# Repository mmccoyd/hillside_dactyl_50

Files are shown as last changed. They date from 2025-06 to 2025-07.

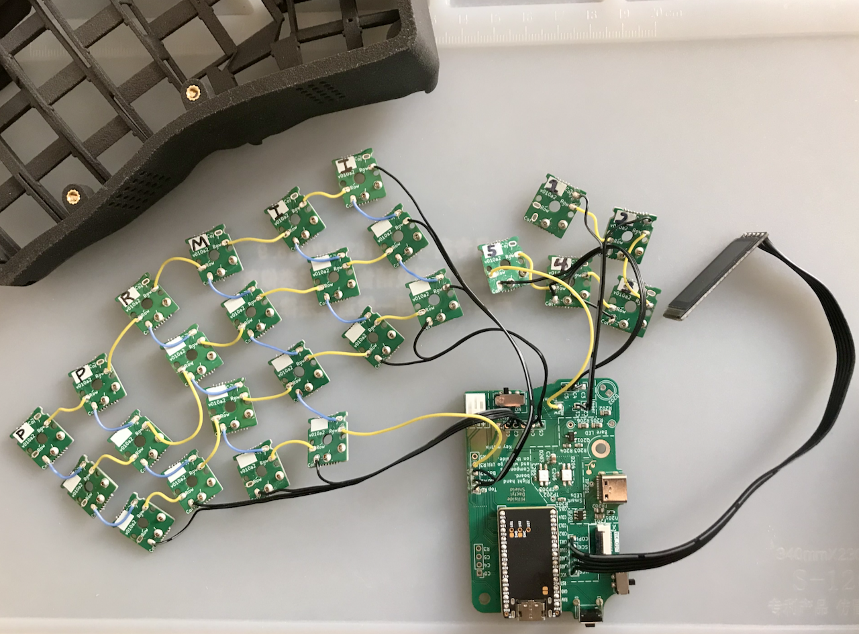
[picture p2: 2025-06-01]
image/D50_build_boards.png

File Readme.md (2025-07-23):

# Hillside Dactyl 50

D50 above

The Hillside Dactyl 50 is a small contoured-keywell ergonomic keyboard
    with three choc-spaced rows of six per side.
This repository has the [body files](./stl/),
    and describes parts and assembly in the 
    [wiki](https://github.com/mmccoyd/hillside_dactyl_50/wiki).

Two other repositories have the PCB files

-   [Amoeba Choc14](https://github.com/mmccoyd/hillside_amoeba_choc14)
    to wire the switches and diodes to create the key matrix.
-   [Hillside Dactyl Shield](https://github.com/mmccoyd/hillside_dactyl_shield)
    to connect the MCU, keys, display, and LEDs.

Though still in development, it has been reliable and comfortable.
See the [Chgange log](./ChangeLog.md) for known issues, but
    I hope you find the board useful.

## Features

-   Three main rows of six, a lower row of two, five thumb keys, and 50 keys
    total.
-   A keywell with 15° column curve, and 15° tent built in.
-   A [Dactyl](https://github.com/adereth/dactyl-keyboard) style thumb cluster
    with a pressing-down motion not a
    gripping one.
-   Choc v1 18 x 17 mm spacing, often nicer for medium or smaller hands.
-   Wireless focused, yet with a wired split USB-C with ESD protection.
-   An external switches header for foot pedals, but case drilling would be
    needed.
-   Default key maps for
    [ZMK](https://github.com/mmccoyd/zmk-hillsideD50) as an external module and
    [QMK](https://github.com/mmccoyd/qmk_firmware/tree/hillside_d50/keyboards/hillside/d50)
    as a branch on a fork.

### Non-Features

-   Switch insertion or replacement externally.
    The case needs to be open to press the amoebas up onto the switches.
    The switches snap into the case, but the amoeba don't.
    The amoeba are held in place by a tight grip on the switch's plastic posts.
    Switches popping out is rare when dropped, but is possible.
    Iterating on this is on my list of longer term items.
-   Per key RGB.
    The amoebas don't have much space.
    It would be cool and might be possible, but is low on my priority list.

## Future

For non-breaking changes:
    the display corner could use more smoothing,
    front magnets spots would allow a palm rest,
    and, as a larger change, a CNC steel bottom plate would give a wider
    base for tenting adjustments and could lower the height a few mm.

The development branch folder
    [stl_dev/](https://github.com/mmccoyd/hillside_dactyl_50/tree/dev/stl_dev)
    may have *untested* files with some of these changes.

Eventually there will be a breaking change to eliminate the external recesses
    for the USB plug overmolding.
A matching new shield design will be needed that extends the USB into the
    inner walls.
But this will be a while.

I don't foresee changes to the basic key configuration,
    such as a five column version.
But I'm working to release STEP and source files for the amoeba socket
    to help others who want to create small choc dactyls.

## License

This work is licensed under a
[Creative Commons Attribution-NonCommercial-ShareAlike 4.0 International](
https://creativecommons.org/licenses/by-nc-sa/4.0/) license.

## See also

This Dactyl evolved from my ergonomic but flat
    [Hillside keyboards](https://github.com/mmccoyd/hillside),
    which offer easier starting points for those new to small choc-spaced
    ergonomic boards.

The general reasons for
    [split contoured-keywells](https://www.ergocanada.com/detailed_specification_pages/kinesis_corporation_advantage360_pro_contoured_keyboard.html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)
    and [small keyboards](https://40s.wiki/en/why) may explain why
    this board can be nice to use.

This Dactyl fits me well and I think likely others with medium hands.
But a roughly good fit is important in a Dactyl, so the below are valuable
    alternatives.

Some prebuild Dactyls include
    the larger [Kinesis Advantage 360](https://kinesis-ergo.com/shop/adv360pro/)
    and [MoErgo Glove 80](https://www.moergo.com/);
    while [Bastard Keyboards](https://bastardkb.com/) has prebuilt
    medium to small
    [Dactyl Manuforms](https://github.com/abstracthat/dactyl-manuform).
Some argue that the original
    [Dactyl](https://github.com/adereth/dactyl-keyboard)
    is gentler on the thumb joint and wrist than the
    [Dactyl Manuform](https://github.com/abstracthat/dactyl-manuform) is.
The Glove 80 is the only of these prebuilt with choc spaced switches, 
    which are nice for medium or smaller hands.

[Cosmos](https://ryanis.cool/cosmos/) is a great generator for custom Dactyl
    Manuform bodies that can do choc vertical but gives thickness warnings for
    choc horizontal spacing.
It offers a prebuilt option and allows broad changes to board parameters.
Including changing the position and angle of the entire thumb
    cluster, with the select cluster and edit cluster controls,
    to make it more original Dactyl like or not.

Two choc v1 boards with contoured body columns,
    though no home-row height variation, are the
    [juriform36](https://github.com/jurica/juriform36) and the
    [rkbrd3](https://github.com/prepor/rkbrd/tree/main/3).
YellowAfterlife's
    [ergonomic keyboard list](https://yal-tools.github.io/ergo-keyboards/)
    shows a few more contoured keywell options and many flat options.

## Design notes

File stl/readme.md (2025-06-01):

# STL files

The files here are for:

-   Left and right body parts - usually 3D printed in nylon or resin.
    -   Upper
    -   Bottom plate
    -   Keywell wiring aid
    -   Thumb wiring aid
-   Non-sided parts
    -   Magnetic tenting oval - likely laser cut from spring steel.
        A standard phone ring is an alternative.
        But it doesn't offer as much ease of tenting adjustment or angle.
    -   Display mount washer - likely laser cut from spring steel.
        There are other ways to secure the display, such as hot glue
        or very likely some normal washer.
        But the case is designed to use the laser cut tenting disk,
        so a laser cut washer is easy to source with that.
    -   Rear laptop hook - usually 3D printed

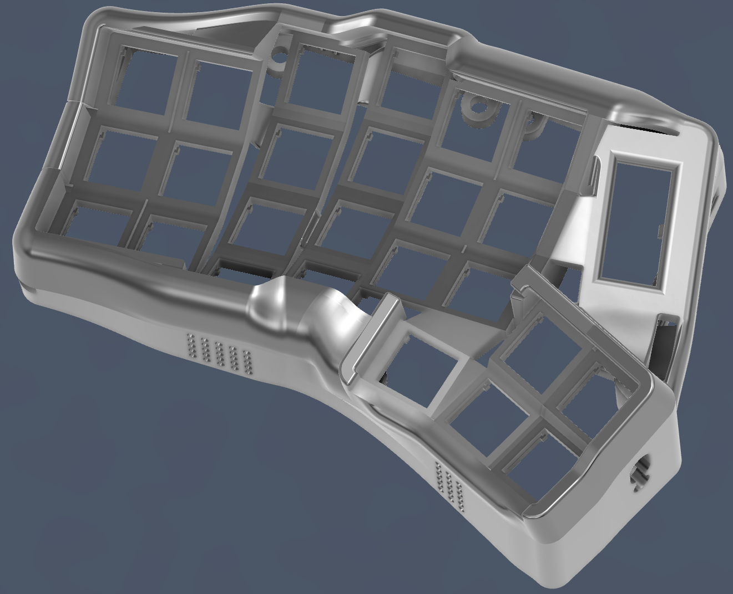
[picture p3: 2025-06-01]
image/D50_render_left.png

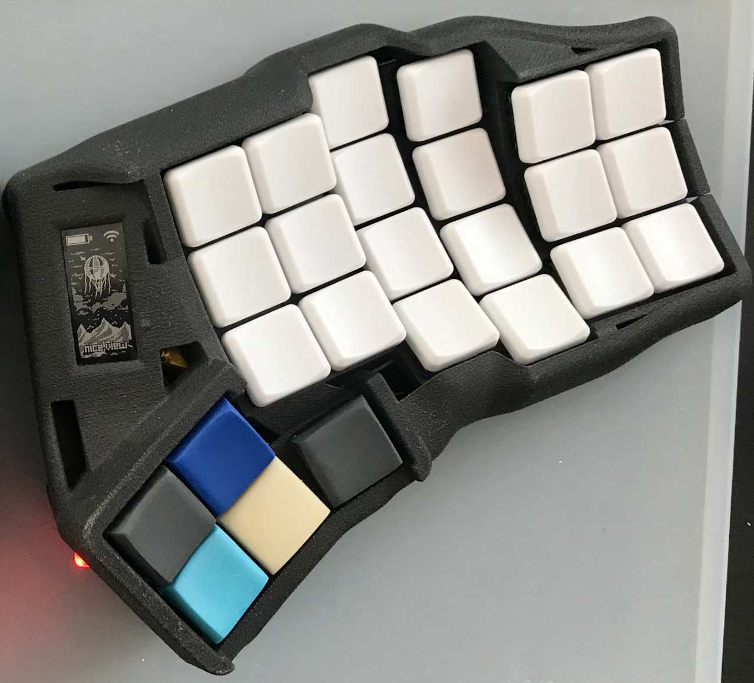
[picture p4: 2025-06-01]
image/D50_right.png

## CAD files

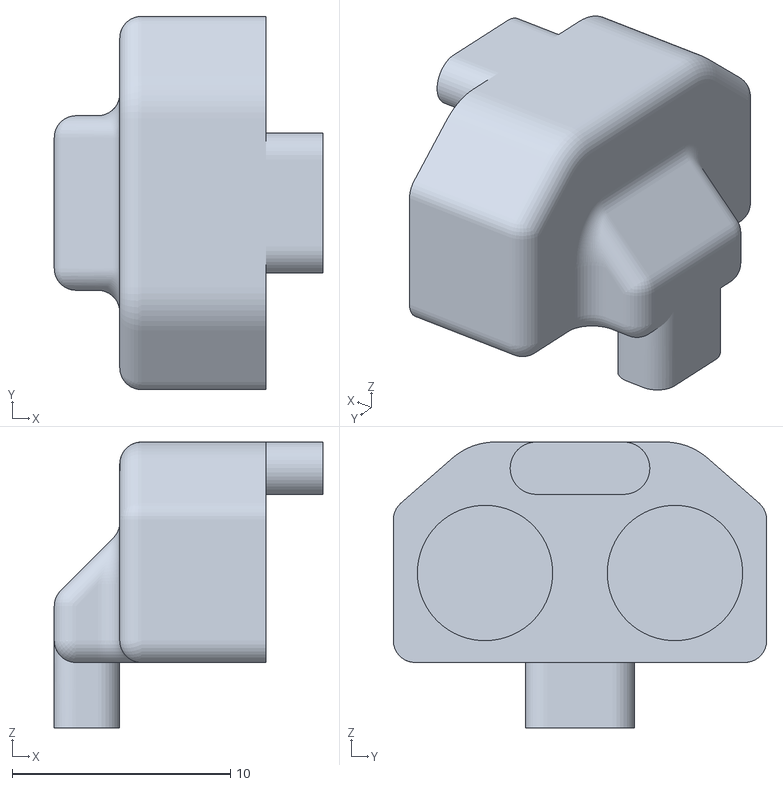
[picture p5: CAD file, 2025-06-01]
stl/HilD50_hook.stl
12.3 x 17.1 x 13.1

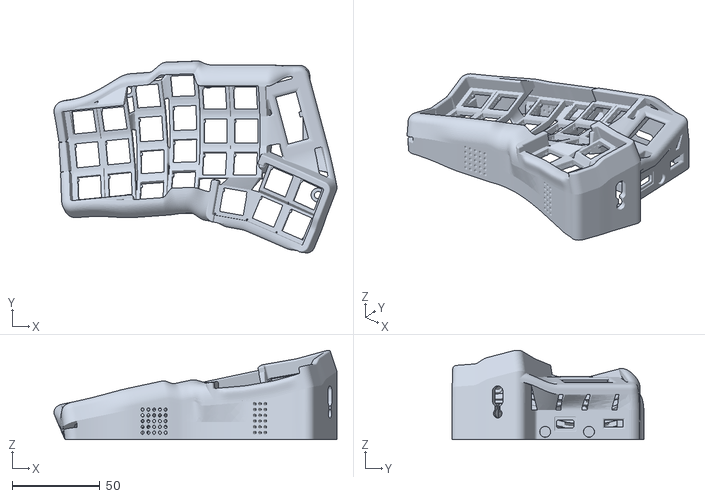
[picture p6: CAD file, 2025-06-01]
stl/left/HilD50_upper_L.stl
161.7 x 109.6 x 51.0

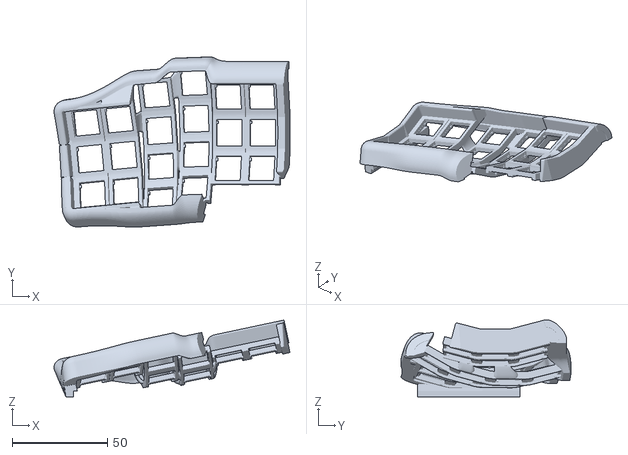
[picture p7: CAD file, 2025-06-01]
stl/left/HilD50_keywell_L.stl
124.2 x 89.5 x 40.5

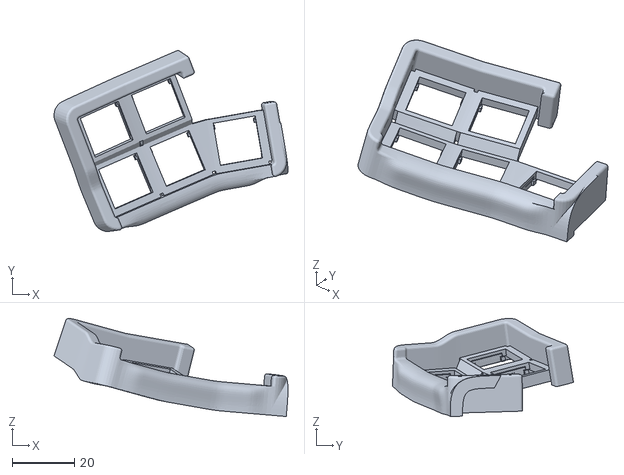
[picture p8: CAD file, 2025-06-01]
stl/right/HilD50_thumb_R.stl
75.3 x 58.3 x 31.6

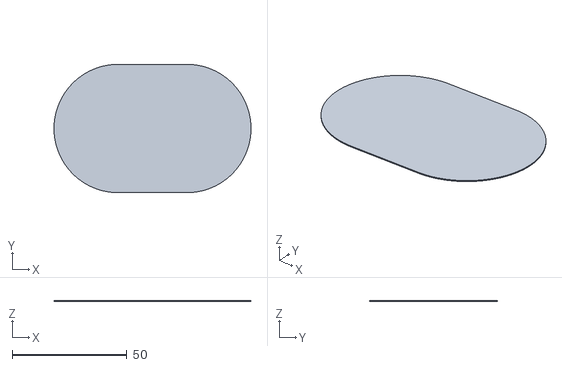
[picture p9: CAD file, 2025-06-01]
stl/HilD50_mag_mount.stl
86.0 x 56.0 x 0.38

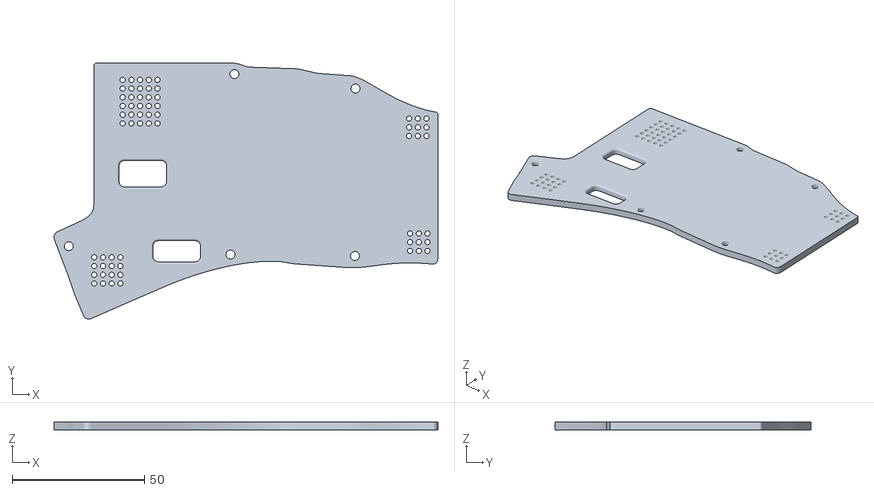
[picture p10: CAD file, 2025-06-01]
stl/right/HilD50_bottom_R.stl
145.4 x 97.0 x 3.00

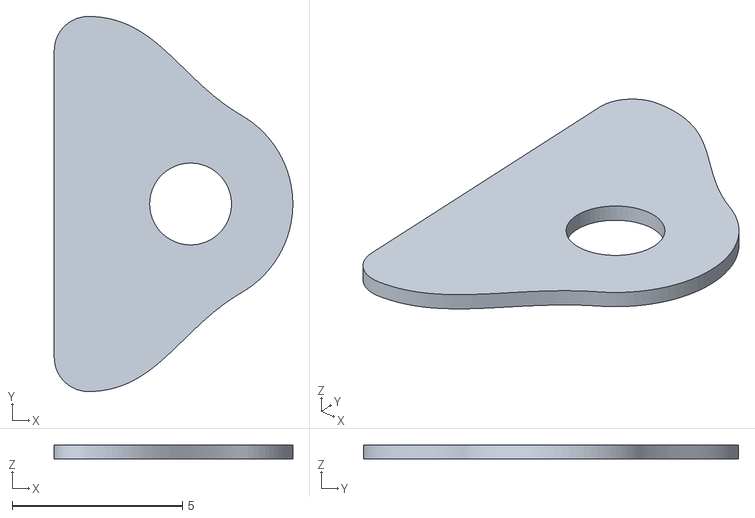
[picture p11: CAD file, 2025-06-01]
stl/HilD50_disp_washer.stl
7.00 x 11.0 x 0.4

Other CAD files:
stl/right/HilD50_upper_R.stl
stl/left/HilD50_thumb_L.stl
stl/left/HilD50_bottom_L.stl
stl/right/HilD50_keywell_R.stl

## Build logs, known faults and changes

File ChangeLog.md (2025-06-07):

# Change Log for the Hillside Dactyl 50 body

## v0.1.0-alpha.3

Better display position and mounting, LED hole, wall grills not open panels.

### Known issues

-   Fully screwing in the display screw pushes up a small bump in the case top
    around the display.
-   The USB holes work with the cables I have,
    but the split one may be too deep for some cables and the rear is inelegant.

### Changes

Breaking change (with respect to the shield)

This moves the bottom LED and LED switch holes to reflect changes made by the
0.1.0-alpha.3 shield. Using the bottom LEDs of an alpha.2 shield would require
cutting some extra holes in the alpha.3 body bottom plate.

The major changes are fixing display mounting and adding a bare LED mount hole.

-   Display
    -   Tilt sideways 10° for visibility and interior mounting space
    -   Move down to not bump up from index home row
-   Display socket
    -   Notch on outside wall for securing display
    -   Four holes for securing display, away from central components
    -   Wider margin before outside wall, though may shorten later
-   Wall
    -   LED hole, round with a slot/open viewing or secondary hole.
    -   Hole grills on the flat areas, instead of open panels.
    -   Smoother front bottom edge and thumb-keywell transition.
-   Key switch socket
    -   Tighter clip-in. Chamfer height reduced to 0.3 mm from 0.5 mm.
-   MCU corner
    -   Rear USB-C hole smaller inner hole, with generous outer hole
        -   Inner: 5 mm tall, 9 mm straight top part
        -   Outer: 9 mm tall, 17 mm wide, 1 mm corners, 2.5 mm recessed
            for the plug's plastic part
        -   (Before that, tested it with -2 mm width and height from alpha.2,
            but plastic plug didn't fit.)
    -   Screw hole for bottom plate moved away from PCB for install clearance.
    -   Taller corner column to strengthen body after putting bigger holes in
        the MCU corner walls.
-   Screw heat insert
    -   Loosen diameter back to 4.1 mm from 4.0 mm.
-   Bottom plate
    -   LED holes moved to the new alpha.3 shield positions
    -   Screw recess add .3 mm depth
    -   Magnetic recess add .1 mm depth to .5 mm.
    -   Grid hole spacing 3.3 mm to avoid thin wall warnings.
-   Neither keywell nor thumb cluster layout changes.
-   Thumbs: reduce the extra front lip

## v0.1.0-alpha.2

Tighter thumb cluster, recess for magnetic mount, reset switch on back.
Not released.

### Known issues

-   Display takes cutting into the wall a little to mount.
-   Base screws stick out a hair.

### Big picture changes

Case

-   Thumb cluster tighter
    -   The reach and center keys are in a grid to be closer, not an arc.
    -   Upper 0.2 mm back, not 1 mm; but still 3 mm up, 10° forward.
    -   Still
        -   10° splay from the single tucked key to the main four
        -   Side caps 5° inward
-   Fit
    -   Thumbs a little higher above key well plane, about 2 mm
    -   Pinkie splay reduced to 1.5° (from 3°)
-   Tented height lowered by moving pinkie case edge inward by 3.5 mm at bottom
-   Wall shroud around keycaps higher
    -   Up 3 mm, to 8 mm from 5 mm
    -   Index column and upper thumb shrouds
-   USB rear has room for 90° plug and cable
    -   Push MCU wall back 3 mm.
    -   Tighten back wall on middle and ring, gaining 1.8 mm
-   MCU corner
    -   Has support shelf for bottom plate in the corner
    -   Wall slants from rear to front instead of straight forward then out
    -   Corner and PCB moved 4 mm inward to give split-USB cable more room
-   Wall magnet mounting holes for a laptop hook or uni-body bridge.
-   Screw insert inside diameter reduced to 4.0 mm from 4.1 mm.
-   Switch socket
    -   Clip-in tighter with chamfer reduced to 0.5 mm from 0.6 mm.
    -   Pushes PCB .36 mm further down for Mill-Max socket lip
-   Bottom plate recess for phone mag mount.
-   Edge on front is softer
    -   Extend middle column's lower guard down
    -   Move lower screw inward and toward the back

Shield

-   USB split uses crossed UART TX/RX data lines
-   Reset is on back for easier grip, and power on side, swapping locations.

### Inner detail changes

-   Column end cap sketches protect key caps and transition to down

## v0.1.0-alpha.1

The original. It worked well but could be improved. Not released.

Alpha.1's thumb cluster setup:

-  Cluster displacements:
    -   5 mm down, 12 mm over to center side edge of tucked
-   Column splay : key well vertical : 10° : tuck : 13 : middle : 15 : reach
-   Tilt: sides 5° inward, upper 10° forward
-   Upper center and side: 3 mm up, 1 mm back

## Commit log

2024-03-30 doc: tighter readme, case around breakout, amoeba
2025-05-14 doc: stl file for easy viewing
2025-06-01 feat: stl for alpha.3
    [HilD50_bottom_L.stl, HilD50_bottom_R.stl, HilD50_disp_washer.stl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]
2025-06-03 doc: tighten readme
2025-06-29 doc: readme image of full board
